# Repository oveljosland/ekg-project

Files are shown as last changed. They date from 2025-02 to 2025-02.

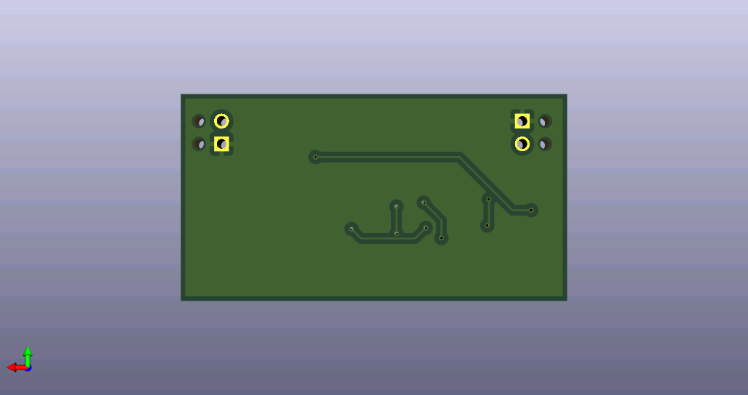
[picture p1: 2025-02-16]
submission/bottom.png

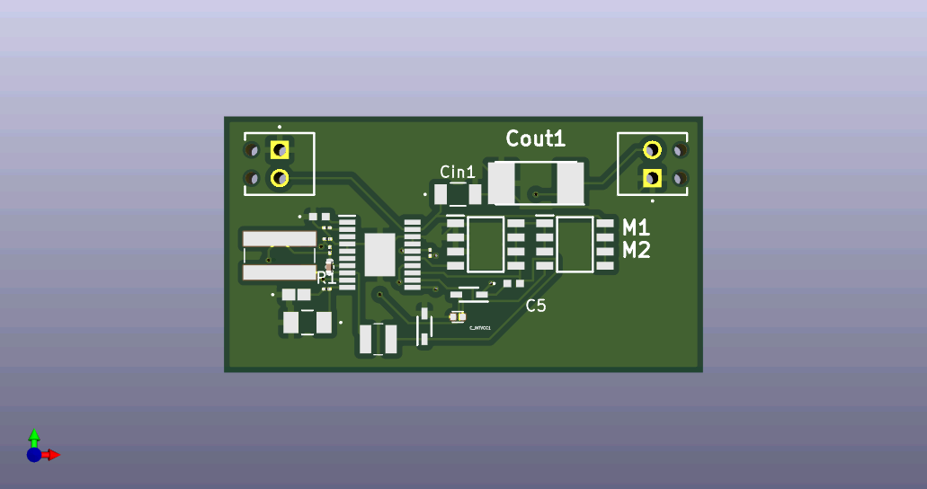
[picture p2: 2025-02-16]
submission/top.png

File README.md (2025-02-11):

# EKG Hardware Project

⚠️ Note: This project is a work in progress. Features and documentation may change frequently.

## Overview
This repository contains the design and documentation files for an EKG hardware project in an Electronics Design course. The project includes schematics, PCB layouts, useful scripts, and other design resources created using **KiCad**.

## Features
- **Modular design**: Allows easy modifications and improvements.
- **Open-source**: All design files and documentation are freely available.

## Repository Contents
- `ekg-interface/`- Design files for the EKG interface.
- `step-down/` - Design files for the step-down converter.

## Tools Used
- **KiCad** - Open-source PCB design tool.
- **LTspice** - Circuit simulation.

## Getting Started
1. Clone this repository:
   ```sh
   git clone https://github.com/oveljosland/ekg-project.git
   ```
2. Open the schematics in **KiCad** or other EDA software.
3. Modify and generate PCB layout as needed.
4. Export Gerber files and fabricate the PCB.
5. Assemble and test!

## License
This project is licensed under the **MIT License**. See [LICENSE](LICENSE) for details.

## Contact
For questions or feedback, feel free to reach out via [GitHub Issues](https://github.com/oveljosland/ekg-project/issues).

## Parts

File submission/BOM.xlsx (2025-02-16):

Line # | Name | Description | Designator | Quantity | TargetPrice | Manufacturer 1 | Manufacturer Part Number 1 | Manufacturer Lifecycle 1 | Supplier 1 | Supplier Part Number 1 | Supplier Unit Price 1 | Supplier Subtotal 1 | Supplier Order Qty 1
 | ERJ-XGNF1003Y | Thick Film Resistors - SMD 01005 100Kohms 1% Halogen-free | R1, R5 | 2 |  | Panasonic | ERJ-XGNF1003Y |  | Mouser | 667-ERJ-XGNF1003Y | 2.53 |  | 0
 | ERJ-XGNF1542Y | Thick Film Resistors - SMD 01005 15.4Kohms 1% Halogen-free | R2 | 1 |  | Panasonic | ERJ-XGNF1542Y |  | Mouser | 667-ERJ-XGNF1542Y | 0.543 |  | 0
 | ERJ-XGNF6042Y | Thick Film Resistors - SMD 01005 60.4Kohms 1% Halogen-free | R3 | 1 |  | Panasonic | ERJ-XGNF6042Y |  | Mouser | 667-ERJ-XGNF6042Y | 0.543 |  | 0
 | KRL6432D-C-R004-F-T5 | Current Sense Resistors - SMD 3W 0.004 Ohm 1% 50ppm | R4 | 1 |  | Susumu | KRL6432D-C-R004-F-T5 |  | Mouser | 754-KRL6432DCR004FT5 | 3 |  | 0
 | ERJ-XGNF4023Y | Thick Film Resistors - SMD 01005 402Kohms 1% Halogen-free | R6 | 1 |  | Panasonic | ERJ-XGNF4023Y |  | Mouser | 667-ERJ-XGNF4023Y | 0.543 |  | 0
 | GRM188C61C226ME01J | Multilayer Ceramic Capacitors MLCC - SMD/SMT 0603 16VDC X5S 22uF 20% | Cin1 | 1 |  | Murata | GRM188C61C226ME01J |  | Mouser | 81-GRM188C61C226ME1J | 4.94 |  | 1
 | TAZH157J010LBSZ0H00 | Tantalum Capacitors - Solid SMD 10V 150uF 0.18Ohms H 5% | Cout1 | 1 |  | KYOCERA AVX | TAZH157J010LBSZ0H00 |  | Mouser | 581-TAZH157J010LBSZ | 124.97 |  | 1
 | CC0402KRX5R7BB225 | Multilayer Ceramic Capacitors MLCC - SMD/SMT 16V 2.2uF X5R 0402 10% HI CV | C1 | 1 |  | YAGEO | CC0402KRX5R7BB225 |  | Mouser | 603-CC402KRX5R7BB225 | 1.54 |  | 0
 | CS0402KRX7R7BB104 | Multilayer Ceramic Capacitors MLCC - SMD/SMT 16 V 0.1uF X7R 0402 10% | C2, C4 | 2 |  | YAGEO | CS0402KRX7R7BB104 |  | Mouser | 603-CS0402KRX7R7BB10 | 1.21 |  | 0
 | CC1206KKX5R7BB226 | Multilayer Ceramic Capacitors MLCC - SMD/SMT 16V 22uF X5R 1206 10% HI CV | C3 | 1 |  | YAGEO | CC1206KKX5R7BB226 |  | Mouser | 603-CC206KKX5R7BB226 | 6.36 |  | 0
 | CS1206JKNPOCBN470 | Multilayer Ceramic Capacitors MLCC - SMD/SMT 1k V 47 pF C0G 1206 5% | C5 | 1 |  | YAGEO | CS1206JKNPOCBN470 |  | Mouser | 603-CS1206JKNPOCBN47 | 2.63 |  | 0
 | AISC-1008F-100G-T | RF Inductors - SMD IND 10.00 uH 0.300 A 2950.00 mOhm | L1 | 1 |  | ABRACON | AISC-1008F-100G-T |  | Mouser | 815-AISC1008F100GT | 3.41 |  | 1
 | LTC3807EFE#PBF | Switching Voltage Regulators L IQ, Sync Buck Cntr w/ 24V Out V Capabi | IC1 | 1 |  | Analog Devices | LTC3807EFE#PBF |  | Mouser | 584-LTC3807EFE#PBF | 95.87 |  | 0
 | IRF7413ZTRPBF | MOSFETs MOSFT 30V 13A 10mOhm 9.5nC | M1, M2 | 2 |  | Infineon Technologies | IRF7413ZTRPBF |  | Mouser | 942-IRF7413ZTRPBF | 9.77 |  | 0
 | 1725656 | Fixed Terminal Blocks 2P 2.54mm 90DEG | J1, J2 | 2 |  | Phoenix Contact | 1725656 |  | Mouser | 651-1725656 | 18.48 |  | 0
 | CMDSH2-3 TR PBFREE | Schottky Diodes & Rectifiers 30V Schottky | D1, D2 | 2 |  | Central Semiconductor | CMDSH2-3 TR PBFREE |  | Mouser | 610-CMDSH2-3 | 7.24 |  | 0

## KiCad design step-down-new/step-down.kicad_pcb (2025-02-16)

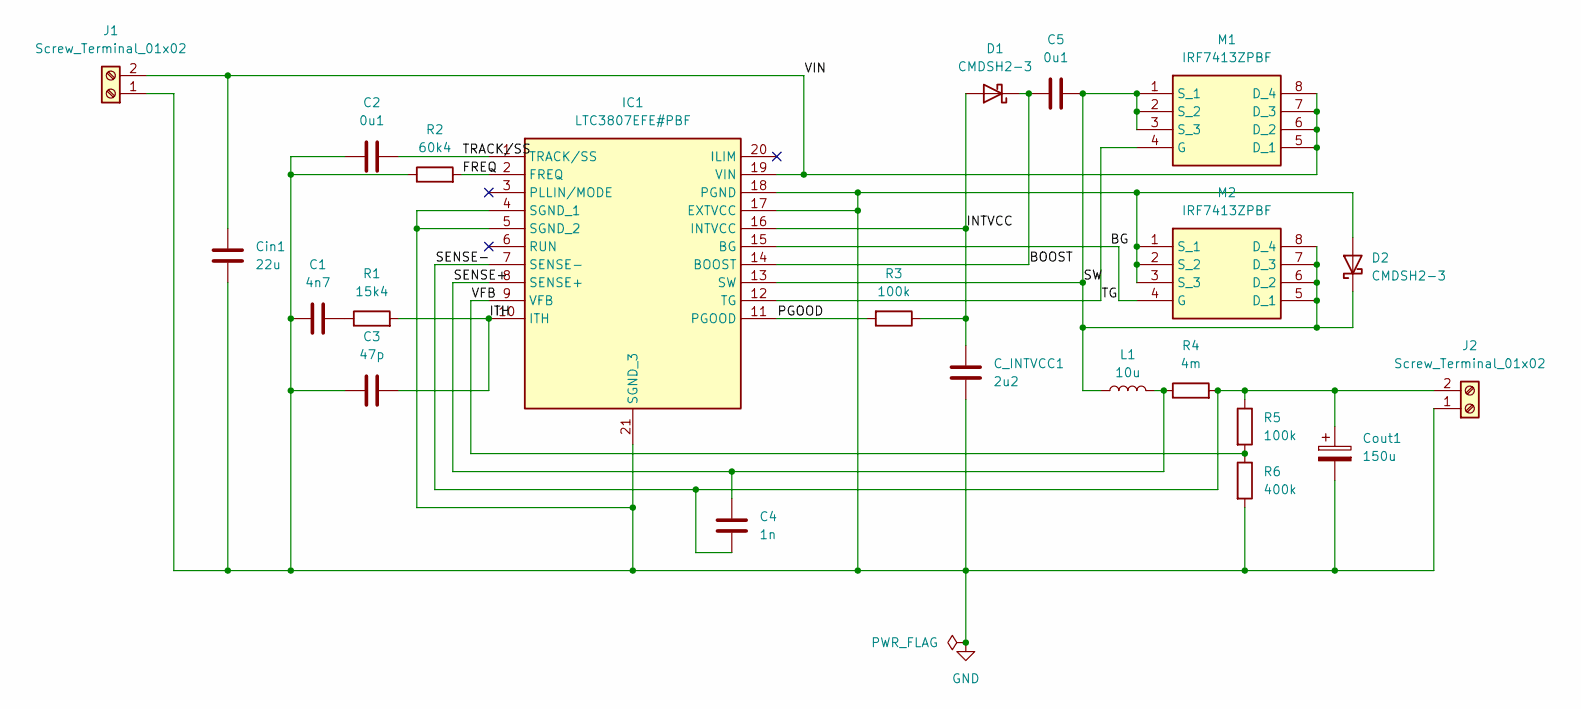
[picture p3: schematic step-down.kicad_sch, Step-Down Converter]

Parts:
C1: 4n7; CAP_CS0603_YAG
C2, C5: 0u1; CAP_CS0402_YAG
C3: 47p; CAP_CS1206_YAG
C4: 1n; C_0402_1005Metric; Mouser Part Number 80-C0402S102K5R
C_INTVCC1: 2u2; CC0402KRX5R7BB225
Cin1: 22u; CAP_CC1206_YAG
Cout1: 150u; TAZH157J010LBSZ0H00
D1, D2: CMDSH2-3; CMDSH2-3_TR_PBFREE
IC1: LTC3807EFE#PBF; Mouser Part Number 584-LTC3807EFE#PBF
J1, J2: Screw_Terminal_01x02; 1725656
L1: 10u; AISC-1008F-100G-T
M1, M2: IRF7413ZPBF; Mouser Part Number 942-IRF7413ZPBF
R1: 15k4; R_01005_0402Metric
R2: 60k4; R_01005_0402Metric
R3, R5: 100k; R_01005_0402Metric
R4: 4m; KRL6432D-C-R004-F-T5
R6: 400k; R_01005_0402Metric

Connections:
/BG: IC1.15 (BG), M2.4 (G)
/BOOST: C5.1, D1.1 (K), IC1.14 (BOOST)
/FREQ: IC1.2 (FREQ), R2.2
/INTVCC: C_INTVCC1.1, D1.2 (A), IC1.16 (INTVCC), R3.1
/ITH: C3.1, IC1.10 (ITH), R1.2
/PGOOD: IC1.11 (PGOOD), R3.2
/SENSE+: C4.1, IC1.8 (SENSE+), L1.2, R4.1
/SENSE-: C4.2, Cout1.1, IC1.7 (SENSE-), J2.2, R4.2, R5.1
/SW: C5.2, D2.1 (K), IC1.13 (SW), L1.1, M1.1 (S_1), M1.2 (S_2), M1.3 (S_3), M2.5 (D_1), M2.6 (D_2), M2.7 (D_3), M2.8 (D_4)
/TG: IC1.12 (TG), M1.4 (G)
/TRACK/SS: C2.2, IC1.1 (TRACK/SS)
/VFB: IC1.9 (VFB), R5.2, R6.1
/VIN: Cin1.1, IC1.19 (VIN), J1.2, M1.5 (D_1), M1.6 (D_2), M1.7 (D_3), M1.8 (D_4)
GND: C1.1, C2.1, C3.2, C_INTVCC1.2, Cin1.2, Cout1.2, D2.2 (A), IC1.4 (SGND_1), IC1.5 (SGND_2), IC1.17 (EXTVCC), IC1.18 (PGND), IC1.21 (SGND_3), J1.1, J2.1, M2.1 (S_1), M2.2 (S_2), M2.3 (S_3), R2.1, R6.2
unnamed: C1.2, R1.1

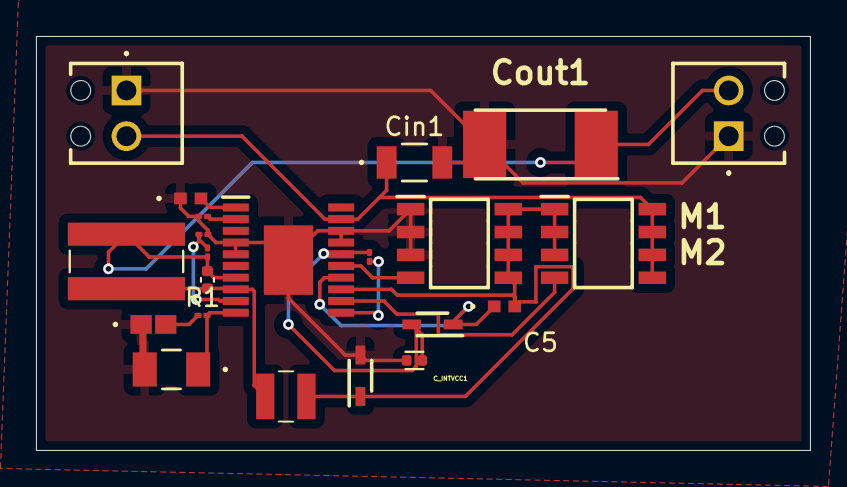
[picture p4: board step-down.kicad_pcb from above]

Board: 2 copper layers, 43.0 x 23.0 mm, 22 parts (0 on the bottom side), 15 nets.

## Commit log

2025-02-11 added ekg interfacing circuit
    [ekg-interface.kicad_pcb, ekg-interface.kicad_sch]
2025-02-12 set components
    [step-down.kicad_sch]
2025-02-12 added components
    [step-down.kicad_sch]
2025-02-12 assigned footprints
    [step-down.kicad_sch]
2025-02-12 assigned footprint L1: Bourns SRP6060FA
    [step-down.kicad_sch]
2025-02-12 add pcb
    [step-down.kicad_pcb, step-down.kicad_sch]
2025-02-12 small change
    [step-down.kicad_pcb]
2025-02-14 Add files via upload
    beep boop
    [step-down.kicad_pcb, step-down.kicad_sch]
2025-02-14 added v2 to step-down2/
    [step-down.kicad_pcb, step-down.kicad_sch, step-down2.kicad_pcb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]
2025-02-14 fixed mosfet connections
    [step-down.kicad_sch]
2025-02-14 gnd fix
    [step-down.kicad_sch]
2025-02-14 fixed ERC error
    [step-down.kicad_sch]
2025-02-14 fixed all ERC errors
    [step-down.kicad_sch]
2025-02-16 new version
    [step-down-B_Cu.gbr, step-down-B_Mask.gbr, step-down-B_Paste.gbr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]
2025-02-16 added images and shc, pcb to submissions
    [step-down.kicad_pcb]
